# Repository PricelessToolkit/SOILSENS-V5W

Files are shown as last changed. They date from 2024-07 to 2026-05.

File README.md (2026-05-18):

<div align="center">
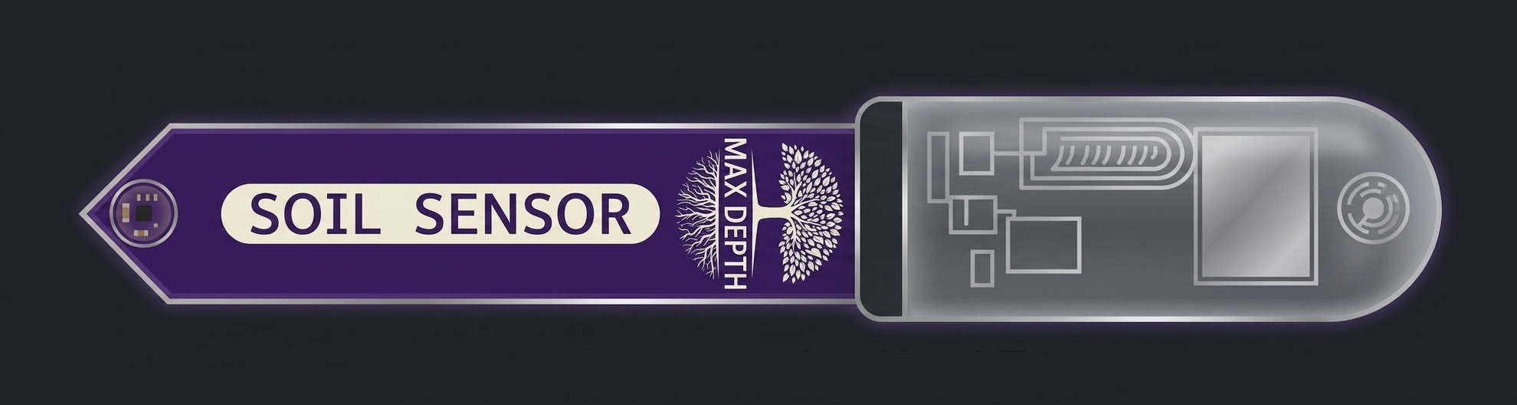
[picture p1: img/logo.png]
SoilSens-V5W
  

🤗 Please consider subscribing to my YouTube channel. Your subscription goes a long way toward supporting my work. If you would like to contribute even more, you can also buy me a coffee.
  
  [Shop](https://www.pricelesstoolkit.com) | [YouTube](https://www.youtube.com/watch?v=jbIuT4Cmzdk&t=36s)
  
</div>
<p align="center">
  <a href="https://ko-fi.com/U6U2QLAF8">
    
  </a>
</p>

____________

# Wireless "SOILSENS-V5W" and Wired ["SOILSENS-V5"](https://github.com/PricelessToolkit/SOILSENS-V5)

The SOILSENS-V5W is a wireless capacitive soil moisture sensor that supports both `ESP-NOW` and `Wi-Fi` connectivity. It also measures soil temperature, air temperature, air humidity, and ambient light. The capacitive sensing electrodes are embedded inside the PCB, which helps protect them from direct exposure. The sensor is compact, power-efficient, and designed for long-range communication in ESP-NOW mode. It can be configured without reflashing and supports MQTT auto-discovery through CapiBridge or direct Wi-Fi MQTT integration, making it fully compatible with Home Assistant.

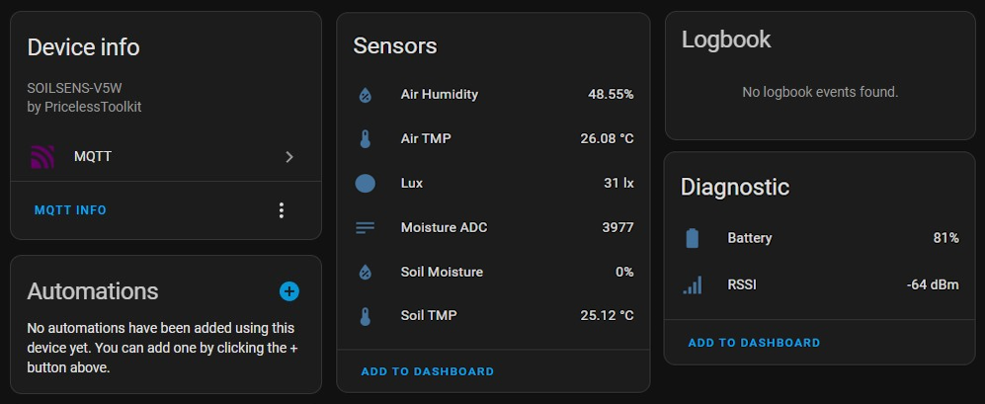
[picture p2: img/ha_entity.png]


## 🛒 Where to Buy https://www.PricelessToolkit.com

## 📣 Updates, Bugfixes, and Breaking Changes

- **18.04.2026** - Improved configuration portal and calibration workflow.
- - Added a cleaner configuration-only web UI with simpler setup for ESP-NOW, Fast-WIFI, and Basic-WIFI.
- - Added web-based soil calibration with live raw value preview plus dedicated Dry Soil and Wet Soil capture buttons.
- - Added Reset to Default directly inside the web interface, making recovery and reconfiguration easier.
- **12.03.2026** - Bugfix / compatibility update.
- - Fixed compilation for ESP32 Arduino Core v3.3.7 and AHT20 v1.0.2.
- - Tested with ArduinoJson v7.4.3, PubSubClient v2.8, and SparkFun TMP102 Breakout v1.1.2.
- **14.05.2025** - Added FailSafe, if it can't connect to WIFI or MQTT, it will power off after 15s.
- **21.03.2025** - Added Basic WIFI mode.

____________

## Product Specification

- **Microcontroller:**
   - ESP32-C3
- **Sensors:**
   - Soil Temperature: TMP102
   - Air Temperature and Humidity: AHT20
   - Light Sensor: ALS-PT19-315C
   - Soil Moisture: PCB Trace in the internal layer
- **Power:**
   - Uses a 1S LiPo battery with a PH2.0 connector
   - Requires an external 1S LiPo charger
- **Buttons:**
   - PRG (Programming)
   - RST (Reset)
   - CAL (Calibration)
   - TRG (Trigger)
- **LED Indicators:**
   - Green LED: Power indicator
   - Blue LED: Configuration mode indicator
- **Sensor Reading Interval:**
  - Default: 1 hour
  - Configurable: 5m, 10m, 30m, 1h, and 2h
  - Configuration Method: Adjustable via onboard PCB solder jumpers

### Required

- 1S 250mAh or less LiPo Battery (Connector PH2.0) 35x20x4mm MAX.
   - PricelessToolkit [1S 250mAh PH2.0](https://www.pricelesstoolkit.com/en/products/47-battery-li-po-37v-250mah-ph-20mm-2-pin.html)
   - https://s.click.aliexpress.com/e/_oBG0tjZ
   - https://s.click.aliexpress.com/e/_Dk14vS5
   - https://s.click.aliexpress.com/e/_DE5PfEV
   - Adafruit 150mAh https://www.adafruit.com/product/1317

> [!WARNING] 
> ⚠️ Ensure the battery connector has the correct polarity, as batteries from China sometimes come with random polarity. If it’s incorrect, you can manually swap the wires by gently lifting the plastic retainer on the pin, pulling the wire out, and then reversing the polarity before reinserting it.
> Connecting the battery with reverse polarity will damage the sensor permanently. Double-check the polarity before connecting the battery.

> [!NOTE]
> Lipo Polarity explanation "Adafruit Video" https://youtu.be/ILArrTIMFyM?si=WlTsnVo7XTozZ2FT

- 1S 4.20V LiPo charger.
  - PricelessToolkit [Micro-Charger](https://www.pricelesstoolkit.com/en/products/47-battery-li-po-37v-250mah-ph-20mm-2-pin.html)
  - Adafruit [Micro Lipo ](https://www.adafruit.com/product/1304)

> [!WARNING]  
> ⚠️ Ensure the charger’s maximum charging current does not exceed the battery’s capacity. For example, if the battery is 250mAh, the charger should have a maximum charging current of 250mA or less. Also, check the charger’s polarity, as it can sometimes be reversed.

###  In case of a Firmware update
- Aliexpress
  - [Pogo pin Clamp 6Pin 2.54mm spacing](https://s.click.aliexpress.com/e/_DEHExUb)
- PricelessToolkit
  - [Any 3.3v USB-UART Programmer](https://www.pricelesstoolkit.com/en/projects/33-uniprog-uartupdi-programmer-33v-0741049314412.html)

# Initial Power-On and Default Operation

- SOILSENS-V5W supports `ESP-NOW` and `Wi-Fi` operation.
- By default, the sensor starts in **ESP-NOW** mode.
- In this default mode, no initial setup is required if you are using a compatible [CapiBridge gateway](https://github.com/PricelessToolkit/CapiBridge).
- The default gateway key is `xy`.

| **Feature** | **ESP-NOW** | **Fast-WIFI** | **Basic-WIFI** |
|---|---|---|---|
| **Energy Efficiency** | Highly energy-efficient | ~3x Higher power consumption | ~10+x Higher power consumption |
| **Range** | Long-Range | Short range | Short range |
| **Configuration** | Does not require configuration | Requires network and MQTT configuration | Requires network and MQTT configuration |
| **Broadcasting** | Sensor data can be read from a third device without connecting to a network | Requires connection to a network | Requires connection to a network |
| **Gateway Requirement** | Requires a gateway [Capibridge](https://github.com/PricelessToolkit/CapiBridge) | Does not require a gateway | Does not require a gateway |

## Power Consumption
> [!NOTE]
> Measured using `Power Profiler Kit 2`, with a 250 mAh battery and a 1-hour wake-up interval.

| **Parameter** | **ESP-NOW** | **Fast-WIFI** | **Basic-WIFI** |
|---|---|---|---|
| **Active Duration (seconds)** | 0.55 seconds | 1.5 seconds | 1.5 - 10 seconds |
| **Current During Active Phase** | 40 mA | 47 mA | * |
| **Energy Consumption in Active Phase** | 0.006112 mAh | 0.02 mAh | * |
| **Inactive Duration** | 0.999847 hours | 0.99956 hours | * |
| **Energy Consumption in Inactive Phase** | 0.00007 mAh | 0.00007 mAh | * |
| **Total Energy Consumption** | 0.006182 mAh | 0.02007 mAh | * |
| **Total Hours of Operation** | 40,445 hours | 12,459 hours | * |
| **Total Days of Operation** | 1,685 days | 519 days | * |

(*) Depends on the network topology

## 1. Configuration

To access the configuration settings, follow these steps:

1. **Enter Configuration Mode**
   - Press and hold the **CAL** button.
   - While holding the **CAL** button, power the sensor or brefly press **TRG** button.
   - Keep holding the **CAL** button for more than 2 seconds, then release it.
   - The blue LED will blink, indicating that the sensor has entered configuration mode, the sensor creates a WiFi Access Point named `SOILSENS-V5W`.
   - Disconnect Celular connection "4G/5G" and Connect to `SOILSENS-V5W` WIFI hotspot.
   - Open a web browser and go to `http://192.168.4.1`.

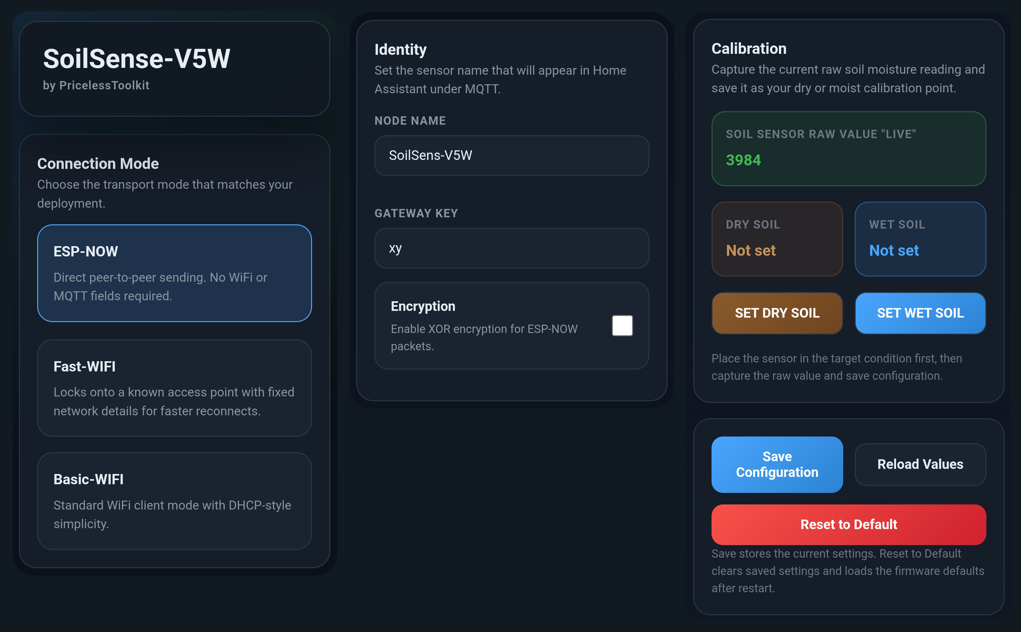
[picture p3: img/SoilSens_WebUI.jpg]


3. **Configure the Sensor in the Web UI**
   - **Connection Mode**
     - **ESP-NOW:** Uses direct ESP-NOW communication with the [CapiBridge gateway](https://github.com/PricelessToolkit/CapiBridge).
     - **Fast-WIFI:** Uses WiFi + MQTT with fixed network details for faster reconnects and lower power use than Basic-WIFI.
     - **Basic-WIFI:** Uses standard WiFi + MQTT setup with fewer required network fields.
   - **Identity**
     - **Sensor Name:** Set the name that will appear in Home Assistant under MQTT.
     - **Gateway Key:** Required only for ESP-NOW mode.
     - **ESP-NOW Encryption:** Optional. If enabled, enter the same key used by your gateway in this format: `["0x4B","0xA3","0x3F","0x9C"]`
   - **WiFi Access**
     - **WiFi SSID:** Enter your 2.4 GHz WiFi network name.
     - **Password:** Enter the WiFi password.
   - **Fast-WIFI Network Details**
     - **AP MAC Address:** Use the radio interface MAC address of your access point.
     - **WiFi Channel:** The channel must be fixed on the access point and must match the value entered here.
     - **Local IP:** Use a free IP address from your local network range and reserve it for the sensor.
     - **Gateway / Subnet:** Enter the network details that match your router.
   - **MQTT Broker**
     - Enter your MQTT server IP or hostname, port, username, and password.
     - In most Home Assistant installations, the MQTT server IP is the same as the Home Assistant IP, and the port is usually `1883`.

4. **Save or Reset**
   - Click **Save Configuration** to store the current settings and power off the sensor.
   - Click **Reload Values** to refresh the page and reload the currently saved values.
   - Click **Reset to Default** to clear all saved configuration and calibration values and return to the firmware defaults.

> [!NOTE]
> If the LED stays on after Saving configuration in WIFI mode, it means the sensor cannot connect because the SSID, Wi-Fi password, MAC address, Wi-Fi channel, or MQTT credentials are incorrect!

## 2. Calibrating the Soil Moisture Sensor

Accurate soil moisture readings require proper calibration. Follow these steps:

1. Insert the sensor into the dry soil.
   - **Optional** ( For best results, water the soil, wait a couple of days for the soil to settle around the sensor, and then dry out. )
2. Open the web configuration page as described in the configuration section above.
3. Go to the **Calibration** block.
4. Check **SOIL SENSOR RAW VALUE "LIVE"** and wait until the reading is stable.
5. For the dry calibration point:
   - Click **SET DRY SOIL**.
   - Click **Save Configuration** to store the dry calibration value.
6. For the wet calibration point:
   - Water the soil to the maximum moisture level you want to allow. **For best accuracy, let it soak for 5 - 10 minutes.**
   - Reopen the web configuration page as described in the configuration section above.
   - Click **SET WET SOIL**.
7. Click **Save Configuration** to store both calibration values.

> [!NOTE]
> For the best result, avoid moving the sensor during calibration. If the soil composition changes over time, or if sediment builds up around the probe, recalibration may be needed.

> [!IMPORTANT]
> ⚠️ Until dry and wet calibration values are saved, the moisture percentage will remain at `0`.

### WiFi Signal Strength

> [!NOTE]
>  Ensure the Wi-Fi signal strength at the installation point is strong and stable.

| RSSI (dBm) | Signal Quality | Description |
|---|---|---|
| -30 to -50 dBm  | Excellent | Very strong signal, ideal for stable data transmission |
| -51 to -60 dBm  | Good | Strong signal, generally reliable for data |
| -61 to -70 dBm  | Fair | Moderate signal, some minor issues possible, but usable |
| -71 to -80 dBm  | Poor | Weak signal, may experience some data drop |
| -81 to -90 dBm  | Very Poor | Very weak signal, frequent data drop likely |
| Below -90 dBm | Unusable | No effective connection, likely out of range |

## Programming Using Arduino IDE

1. Open the provided code in the Arduino IDE.
2. Install all required libraries.
```c
      
   #include <esp_now.h>
   #include <WiFi.h>
   #include "driver/adc.h"
   #include "esp_adc_cal.h"
   #include "Wire.h"
   #include <SparkFunTMP102.h>
   #include <ArduinoJson.h>
   #include <AHT20.h>
   #include <Preferences.h>
   #include <WebServer.h>
   #include <PubSubClient.h>
           
```
3. Select the appropriate board and port parameters. Refer to the screenshot below for the recommended settings.
       
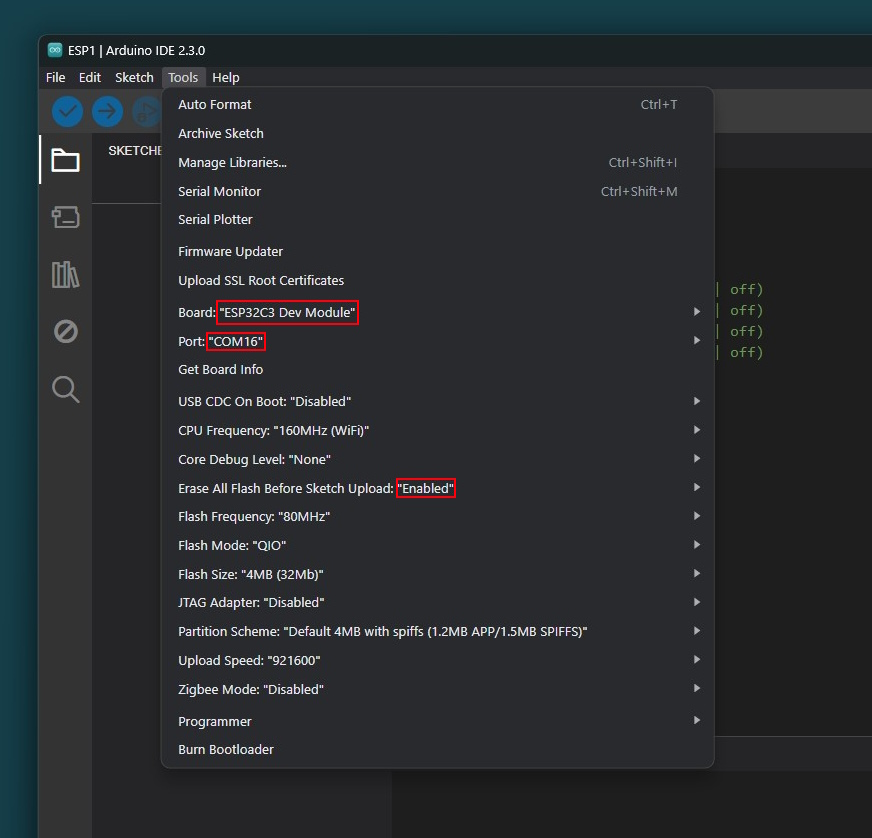
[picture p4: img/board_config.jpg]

       
4. Connect a 3.3V USB-to-TTL adapter to SOILSENS-V5W.

   | Sensor Pin | Adapter Pin |
   |------------|-------------|
   | TX         | RX          |
   | RX         | TX          |
   | 3V3        | 3V3         |
   | GND        | GND         |

5. Press and hold the **PRG** button on the sensor.
6. While holding **PRG**, connect the USB-to-TTL adapter to your computer.
7. Click **Upload** in the Arduino IDE.

## Frequently Asked Questions
### Why is my sensor giving inconsistent readings?
Due to the capacitive sensing principle, readings can vary based on soil moisture, tightness, and insertion depth. Repeated insertions might loosen the soil, affecting subsequent readings.

## 3. Wake-Up Interval

| Solder Jumpers | Interval Selection |
|---|---|
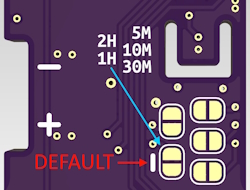
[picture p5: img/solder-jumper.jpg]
|  | You can change the interval by cutting the middle of the `1H` jumper and then bridging the desired jumper with solder. Available base intervals are `5m`, `10m`, `30m`, `1h`, and `2h`. Different combinations are also possible. [Parallel Resistor Calculator](https://www.digikey.fr/en/resources/conversion-calculators/conversion-calculator-parallel-and-series-resistor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) |

If you want to experiment with different wake-up intervals, you can also change the resistor value.

| Time Interval | Resistor Value (kΩ) | Time Interval | Resistor Value (kΩ) |
|---|---|---|---|
| 1 min | 22.00 | 10 min | 57.6 - soldered |
| 2 min | 29.349 | 20 min | 77.579 |
| 3 min | 34.729 | 30 min | 93.1 - soldered |
| 4 min | 39.097 | 40 min | 104.625 |
| 5 min | 42.2 - soldered | 50 min | 115.331 |
| 6 min | 46.301 | 1 h | 124.00 - soldered |
| 7 min | 49.392 | 1h 30min | 149.398 |
| 8 min | 52.224 | 2 h | 169.00 - soldered |
| 9 min | 54.902 |

> [!NOTE]
> The default wake-up interval is 1 hour. Reducing the interval will increase energy consumption.

# DIY

This project is open-source, so you can assemble SOILSENS-V5W yourself. To make the build easier, an interactive HTML BOM file is included in the `PCB` folder. It shows component placement and polarity to reduce assembly errors. A great deal of time and money has gone into making this project open-source. Support through purchasing a ready-made device from www.PricelessToolkit.com, subscribing to the YouTube channel, or buying me a coffee helps fund future projects.

## Schematic
<details>
  <summary>View schematic. Click here</summary>
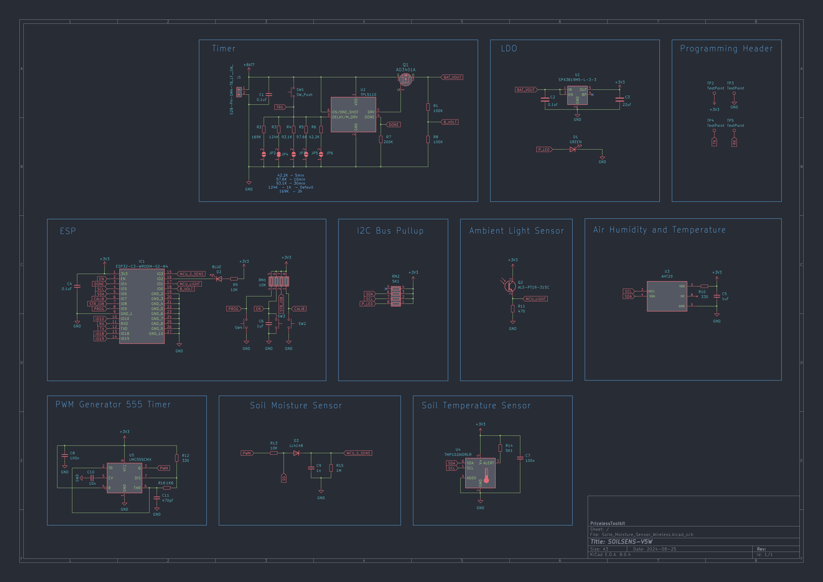
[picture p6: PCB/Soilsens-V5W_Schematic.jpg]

</details>

## 3D-Printed Case
The ideal case material is transparent and UV-resistant. ASA or white ABS is a good choice because it allows enough light to enter for the luminance sensor to work properly. For indoor use, translucent PETG can improve the luminance sensor range, and vent holes help the air temperature and humidity sensors work correctly. For outdoor use, a case without vent holes is recommended to reduce the risk of water ingress during heavy rain.
Glue for case https://s.click.aliexpress.com/e/_DcvGBY9

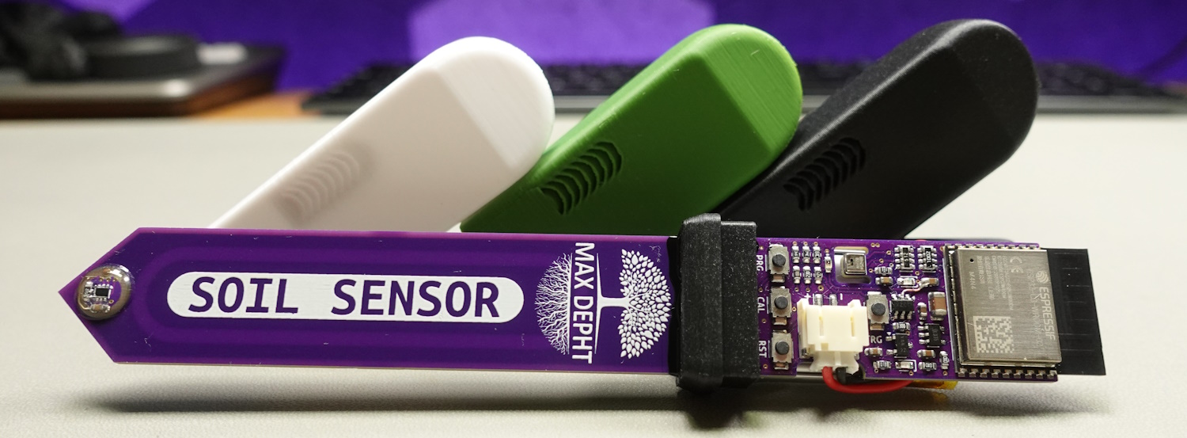
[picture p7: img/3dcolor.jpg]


## Troubleshooting

- Holding the calibration button.
    - More than 2 seconds opens configuration mode.
- When manually pressing the trigger button, the sensor may occasionally stay on and not power off if the button is not released quickly enough. If this happens, simply press the reset button.

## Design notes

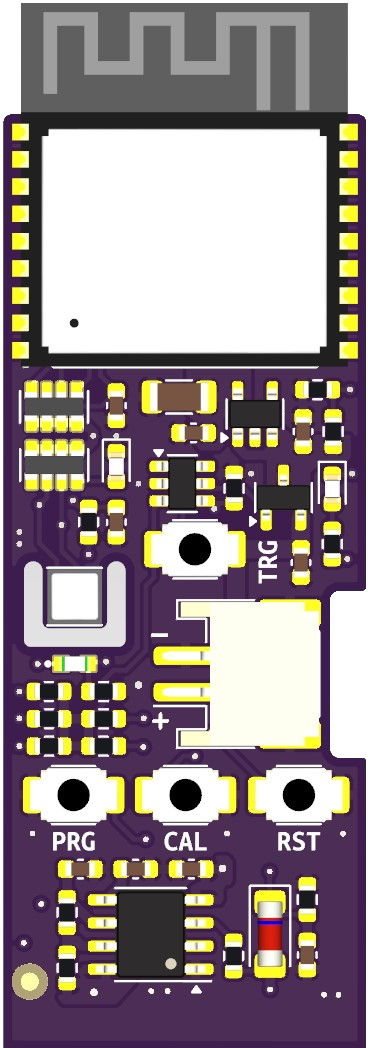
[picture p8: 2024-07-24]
img/sens-kc.png

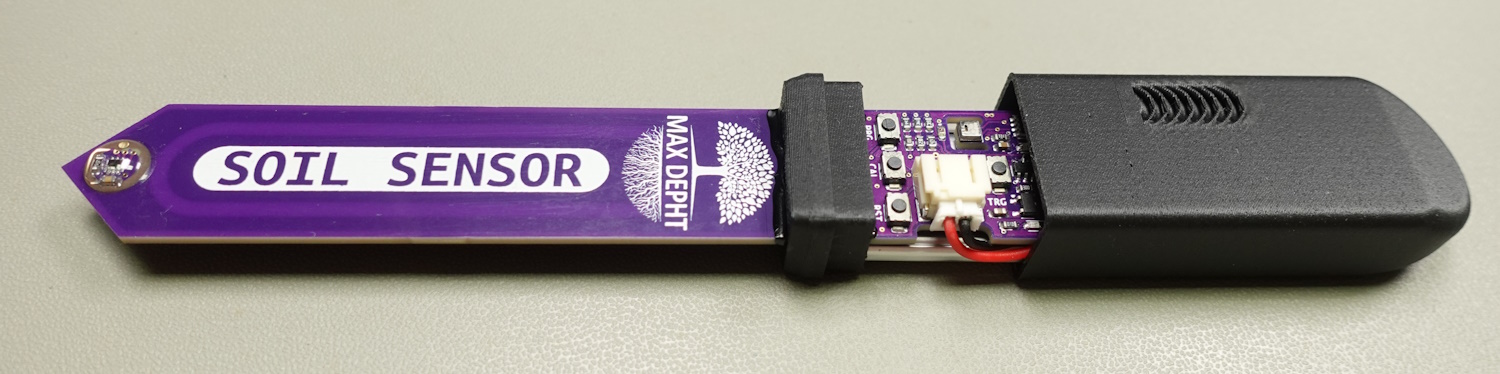
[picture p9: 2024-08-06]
img/header.jpg

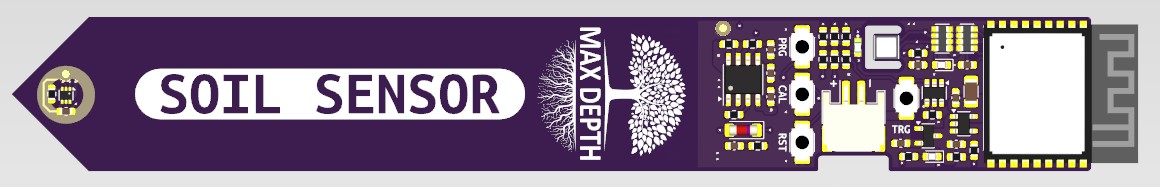
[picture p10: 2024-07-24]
img/sens-kc-full.jpg

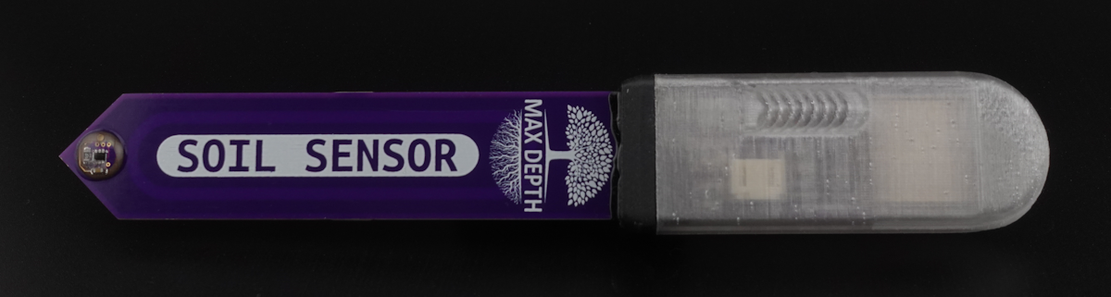
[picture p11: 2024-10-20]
img/sens-cap.png

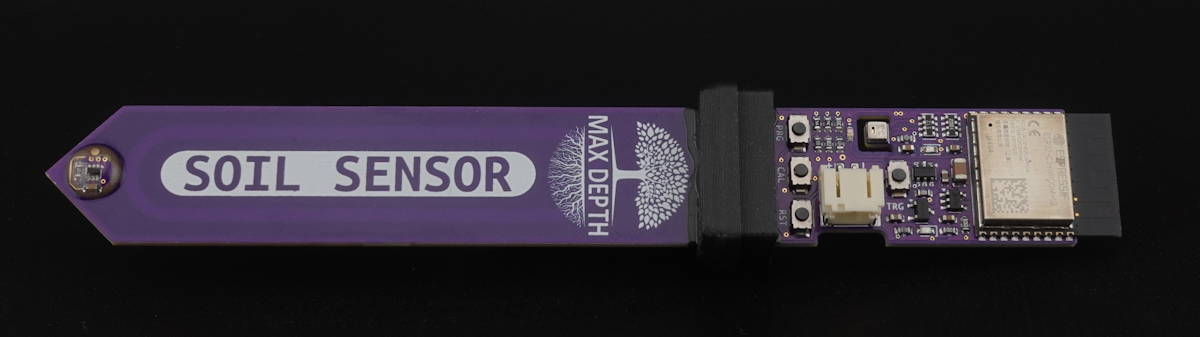
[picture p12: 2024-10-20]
img/sens-nk-pcb.png

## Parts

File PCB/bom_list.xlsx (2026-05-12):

Part ID | Part IPN | Part Name | Quantity | Reference | Supplier_0 | SKU_0
219 | CAP-000219-00 | Capacitor 0603_100nF_10%_50V_X7R - SMD/SMT ROHS | 5.0 | C1, C2, C4, C7, C8 | LCSC | C14663
263 | CAP-000263-00 | Capacitor 0603_1uF_10%_25V_X7R - SMD/SMT ROHS | 2.0 | C5, C6 | LCSC | C59302
334 | CAP-000334-00 | Capacitor 1206_22uF_10%_16V_X5R - SMD/SMT ROHS | 1.0 | C3 | LCSC | C90146
342 | CAP-000342-00 | Capacitor 0603_1nF_10%_50V_X7R - SMD/SMT ROHS | 1.0 | C9 | LCSC | C100040
23 | CAP-000023-00 | Capacitors 0603_10nF_5%_50V_X7R - SMD/SMT ROHS | 1.0 | C10 | LCSC Electronics | C115056
21 | CAP-000021-00 | Capacitors 0603_470pF_5%_50V_NP0 - SMD/SMT ROHS | 1.0 | C11 | LCSC Electronics | C106211
216 | RES-000216-00 | Resistor 0603_100K_1%_75V_100mW - Surface Mount ROHS | 2.0 | R1, R8 | LCSC | C14675
267 | RES-000267-00 | Resistor 0603_10K_1%_75V_100mW - Surface Mount ROHS | 2.0 | R9, R13 | LCSC | C25804
20 | RES-000020-00 | Resistors 0603_330R_1%_75V_100mW - Surface Mount ROHS | 2.0 | R10, R12 | LCSC Electronics | C105881
313 | RES-000313-00 | Resistor 0603_169K_1%_75V_100mW 100ppm/℃ - Surface Mount ROHS | 1.0 | R2 | LCSC Electronics | C137791
11 | RES-000011-00 | Resistors 0603_124K_1%_75V_100mW - Surface Mount ROHS | 1.0 | R3 | LCSC Electronics | C22788
315 | RES-000315-00 | Resistor 0603_93.1K_1%_75V_100mW - Surface Mount ROHS | 1.0 | R4 | LCSC | C2933266
316 | RES-000316-00 | Resistor 0603_57.6K_1%_75V_100mW - Surface Mount ROHS | 1.0 | R5 | LCSC | C2933240
317 | RES-000317-00 | Resistor 0603_42.2K_1%_75V_100mW - Surface Mount ROHS | 1.0 | R6 | LCSC | C273741
312 | RES-000312-00 | Resistor 0603_200K_1%_75V_100mW - Surface Mount ROHS | 1.0 | R7 | LCSC | C105574
340 | RES-000340-00 | Resistors 0603_470R_1%_75V - Surface Mount ROHS | 1.0 | R11 | LCSC | C23179
208 | RES-000208-00 | Resistor 0603_5.1K_1%_50V_100mW - Surface Mount ROHS | 1.0 | R14 | LCSC | C2907044
271 | RES-000271-00 | Resistor 0603_1M_1%_75V_100mW - Surface Mount ROHS | 1.0 | R15 | LCSC | C105578
19 | RES-000019-00 | Resistors 0603_1.6K_1%_75V_100mW - Surface Mount ROHS | 1.0 | R16 | LCSC Electronics | C2930052
53 | DIO-000053-00 | LED 0603_55mW_Yellow-Green - ROHS | 1.0 | D1 | LCSC | C965805
201 | DIO-000201-00 | LED 0603_80mW_Blue XL-1608UBC-04 ROHS | 1.0 | D2 | LCSC | C965807
341 | DIO-000341-00 | Switching Diode LL4148_LL-34_75V 1V@10mA 4ns 200mA LL-34 ROHS | 1.0 | D3 | LCSC | C3011166
64 | PWR-000064-00 | Voltage Regulator SPX3819M5-L-3-3/TR 3.3V 500mA SOT-23-5 (LDO) ROHS | 1.0 | U1 | LCSC Electronics | C9055
73 | ICS-000073-00 | Timer TPL5110DDCT 1.8V~5V SOT-23-6 ROHS | 1.0 | U2 | LCSC Electronics | C125830
339 | ICS-000339-00 | SMD Temperature and Humidity Sensor ROHS | 1.0 | U3 | LCSC | C2757850
336 | ICS-000336-00 | Temperature Sensor TMP102AIDRLR -40℃~+125℃ I2C ±0.5℃ SOT-563 ROHS | 1.0 | U4 | LCSC | C99269
338 | ICS-000338-00 | LMC555M/TR 2-18V SOP-8 Timers ROHS | 1.0 | U5 | LCSC | C356725, C90760, C19193414
122 | MEC-000122-00 | Tactile Switche TS342A2P-WZ NO 50mA Brick nogging SPST SMD ROHS | 4.0 | SW1, SW2, SW3, SW4 | LCSC Electronics | C557591
273 | WIFI-000273-00 | WIFI Module ESP32-C3-WROOM-02-N4 4MB SPI flash, PCB antenna, -40 C +85 C SMD | 1.0 | IC1 | Mouser | 356-ESP32C3WROOM02N4
80 | TRA-000080-00 | MOSFET P-Channel AO3401A 30V 4.2A SOT-23 ROHS | 1.0 | Q1 | LCSC Electronics | C306862
202 | ICS-000202-00 | Ambient Light Sensor ALS-PT19-315C/L177/TR8 0603 SMD ROHS | 1.0 | Q2 | LCSC | C146233
291 | RES-000291-00 | Resistor Network 0603x4_10k_1% 62.5mW ROHS | 1.0 | RN1 | LCSC | C110924
301 | RES-000301-00 | Resistor Network 0603x4_5.1K_5%_62.5mW ±200ppm/℃ ROHS | 1.0 | RN2 | LCSC | C12028
60 | CON-000060-00 | Connector 1x2P_PH_2A_P2mm_Male - ROHS | 1.0 | J1 | LCSC Electronics | C295747
353 |  | SOILSENS-V5W_PCB | 1.0 | PCB
354 |  | SOILSENS-V5W_3D_Enclosure | 1.0

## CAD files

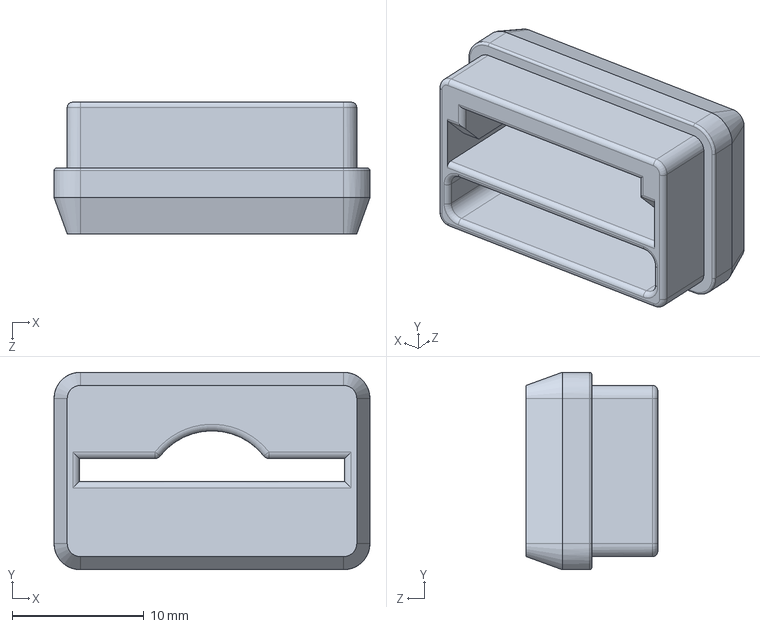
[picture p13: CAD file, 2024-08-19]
3D/SoilSens-V5W_Base_DIY.SLDPRT
24.0 x 15.0 x 10.0 mm

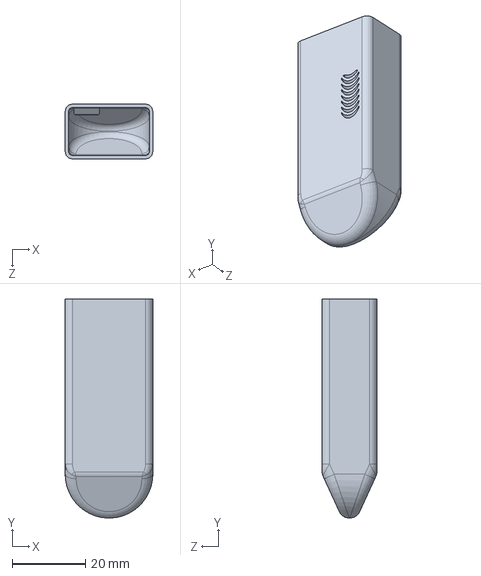
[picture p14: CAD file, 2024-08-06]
3D/SoilSens-V5W_Top_Vent.SLDPRT
24.0 x 60.0 x 15.0 mm

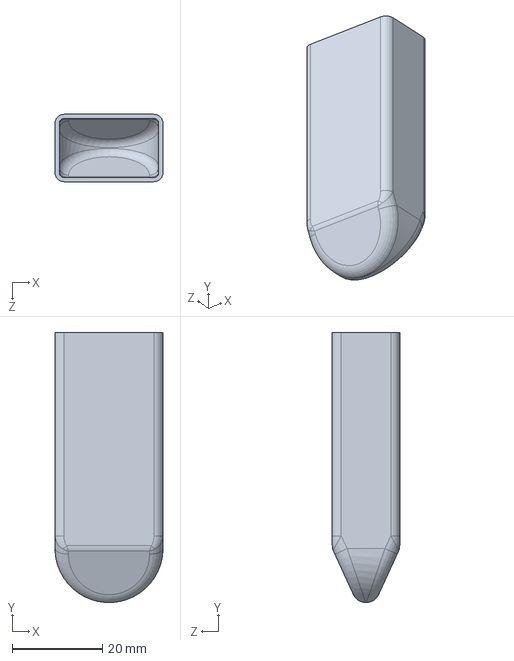
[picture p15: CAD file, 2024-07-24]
3D/SoilSens-V5W_Top.SLDPRT
24.0 x 60.0 x 15.0 mm

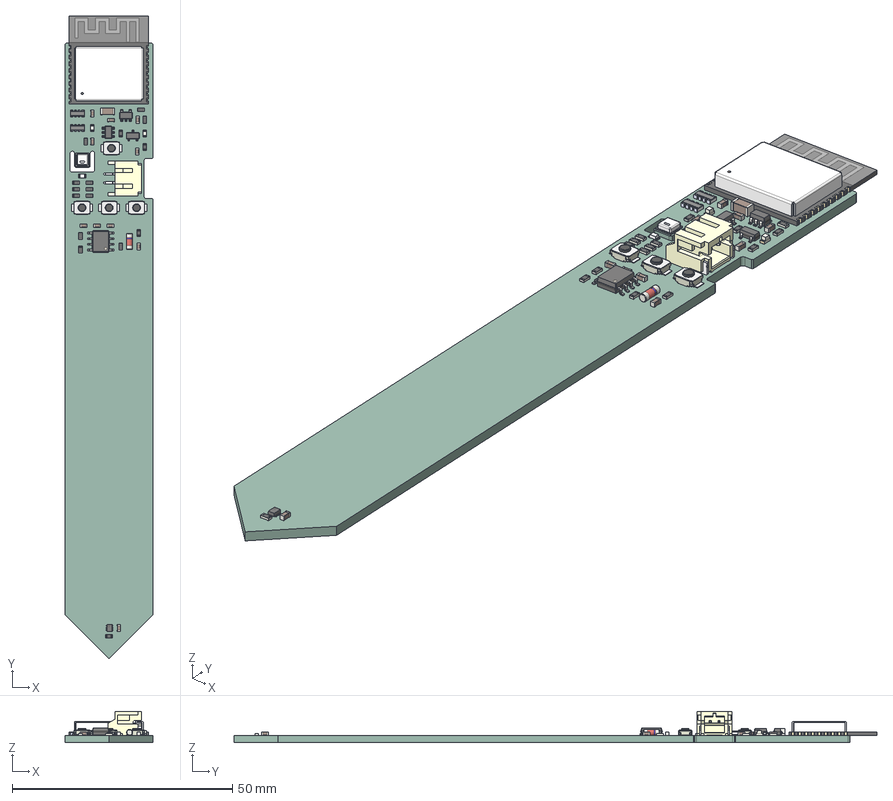
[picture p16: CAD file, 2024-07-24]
3D/Soile_Moisture_Sensor_Wireless.step
20.0 x 146.1 x 7.15 mm
C_0603_1608Metric x 10
R_0603_1608Metric x 16
ALS-PT19-315C(slash)L177(slash)TR8
SW_SPST_B3U-1000P x 4
D_MiniMELF_Standard
SOT-23-3
S2B-PH-SM4-TB(LF)(SN)
SOT_563
SOIC_8_39x49mm_P127mm
YC164-JR-0720KL x 2
LED_0603_1608Metric x 2
SOT_23_6
C_1206_3216Metric
ESP32-C3-WROOM-02-N4
SOT_23_5
AHT20 Sensor v0
_autosave-Soile_Moisture_Sensor_Wireless_PCB

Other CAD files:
3D/SoilSens-V5W_Base.SLDPRT
3D/SoilSens-V5W_Base.STL
3D/SoilSens-V5W_Base_DIY.STL
3D/SoilSens-V5W_Top.STL
3D/SoilSens-V5W_Top_Vent.STL
3D/Soile_Moisture_Sensor_Wireless.SLDASM

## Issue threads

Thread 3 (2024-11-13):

kicad files missing

shufps, 2024-11-13:
It seems there are no KiCad files in the repository.

PricelessToolkit, 2024-11-13:
I don't share KiCad files; only Gerber files and the BOM are provided for self-assembly.

shufps, 2024-11-14:
Why not?

"Copy protection" doesn't make sense because I can replicate your entire KiCad project from your schematic and pictures on a single day.

It's just annoying having to do this but it actually doesn't protect anything by not publishing it :thinking:

PricelessToolkit, 2024-11-14:
1. It protects from generating a 'PnP placement file' and from logo swappers. 2. I’d rather not have to explain my routing choices every two minutes or hear critiques on how it 'should' be done, one or two suggestions per project are fine, but every passerby seems to have a new idea, and I simply don’t have the time. I share the Gerbers for the Home Assistant community, so if someone prefers not to buy the assembled version, they can assemble it themselves as a more affordable option.

Closed 2024-11-13.

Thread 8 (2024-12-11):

MQTT auto-discovery not working with Capibridge

ppkstat, 2024-12-11:
I just finished building my Soilsens. The device appears to function correctly but it is not discovered by MQTT in home assistant.
This is what is beeing received by the Capibridge when triggered:
ESP-NOW Message: {"k":"xy","id":"Soilsens Autopot ","b":65,"l":26,"mo":0,"t":18,"t2":18,"hu":54}

and this is a screenshot of the MQTT explorer:
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

PricelessToolkit, 2024-12-11:
1. Is your Capibridge key "xy"? , make sure that capibridge and soilsens has the same key.
2. "Soilsens Autopot " remove spaces, from the middle and from the end "Soilsens-Autopot" I will add this in the manual!

Closed 2024-12-11.

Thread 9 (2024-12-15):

Soilsens V5W - Text Sensor

DirkTas67, 2024-12-15:
Hello,

I was wondering what the Text sensor is for the Soilsens v5w, I don't know if you shipped it this way to me but I had some problems installing the sensor, I eventualy had to 'reset' it with the 'plugin power/hold the calibration button' trick before it worked but that was after I re-installed the firmware, so now I have a text sensor that is changing rapidly and I wonder if this is good for the battery (still don't have a battery, it is powered directly from usb via pogo pins).

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

DirkTas67, 2024-12-15:
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

This is what the serial monitor tells us.

PricelessToolkit, 2024-12-15:
Hi, Thank you for supporting my work!
The "text" sensor is a raw ADC reading from the "moisture sensor." It can be handy for checking calibration. The serial output is normal but can appear to freak out because the sensor sends data too quickly, with no delay between readings. This happens because you powered it from the programming port, so the sensor can't "unplug itself" from power after sending data once. When you power it with a battery, it will work properly.

Closed 2024-12-16.

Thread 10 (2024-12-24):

Wrong silk mask text

BoguslavskyiR, 2024-12-24:
During flashing first board was discovered that UART contacts have wrond naming

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

PricelessToolkit, 2024-12-24:
Strange. Are you sure that the pinout name on your programmer is correct?

TP4 is TX and it is current.
 https://github.com/PricelessToolkit/SOILSENS-V5W/blob/main/PCB/Soilsens-V5W_Schematic.jpg

BoguslavskyiR, 2024-12-24:
I will double check, but it's not the first time I have used this adapter (DFrobot dfr0065).
But i will check again with another adapter

PricelessToolkit, 2024-12-24:
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

BoguslavskyiR, 2024-12-24:
In this case sorry, but it's very strange, I've been using this dongle for a long time with the rx->tx connection.

PricelessToolkit, 2024-12-24:
No need to apologize! It's all good I’m here for help. If you want to check it yourself, just snap a photo, zoom in, and follow the PCB trace from pin 5. Unfortunately, I couldn’t find a high-quality photo, but this one is the best I’ve seen so far:
https://m.media-amazon.com/images/I/6115v8bCfbL._AC_SL1000_.jpg

Closed 2024-12-24.

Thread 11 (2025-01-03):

Battery

DirkTas67, 2025-01-03:
Hello,

I received 2 sensors yesterday. I added a 250mah battery on one of the sensors and a 200mah on the other sensor. I charged both of them fully and installed then on the sensors and then calibrated the sensors. The one with the 250mah battery showed 100% battery, the one with the 200mah battery showed 85% battery. I then put them in place. a day later the one with the 200mah battery shows now 14% battery and the one with the 250mah battery shows 45%.

update time is still 1 hour.

Is this normal?

Regards Dirk

DirkTas67, 2025-01-03:
I forgot to mention that both of them are working is ESPNOW modus

PricelessToolkit, 2025-01-03:
The green LED always stays on?

DirkTas67, 2025-01-03:
No, the green led is off

PricelessToolkit, 2025-01-03:
If the LED is off, the consumption is 400nAh, so the consumption you describe is impossible. If it turns on every hour, it stays on for approximately 500ms. It basically can't consume that amount of power. When you check the serial output of CapiBridge, is the battery percentage the same as in Home Assistant? and can you check the voltage on battery?

DirkTas67, 2025-01-06:
Ok, after 2 days both batteries were empty.

Second try, charged the 200mah battery again and installed it, it showed 81% but now after 2 days it still shows 81%, this is allready a great improvement, just charged the 250mah battery and inserted it and this one shows 100%, maybe it was just a reset thing. I installed the batteries, calibrated the sensor for correct moisture and placed them in the ground. Maybe a reset is needed. In a few days I check again and let you know.

PricelessToolkit, 2025-01-06:
Even if you don't connect a freshly charged battery (4.20V), after a couple of days, its voltage sags slightly, typically to around ~4.12V. This is a 1-2% drop, depending on the battery's freshness and quality. However, after that, the voltage will stabilize.

An 81% reading on a 4.2V battery is unusual and could be due to variations in the voltage divider resistors. If it bothers you, it can be calibrated by reflashing the firmware.

PricelessToolkit, 2025-01-14:
Does everything work as intended? can I close This issue?

Closed 2025-01-15.

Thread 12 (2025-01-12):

Support for MQTTS and CNAME

tnesztler, 2025-01-12:
# Context

MQTT server is exposed behind a reverse proxy for SSL termination.
This results in the MQTT port being 8883 (default for MQTTS) and hostname being a CNAME, not an IP.

I personally had to expose my MQTT server via a direct IP and standard TCP port (1883) to make it compatible with the soil sensor which is not ideal as that leaves the communication un-encrypted on the air.

Could we make on boot a single DNS request to get the IP, validate the SSL certificate and connect to the MQTT server?
Would that work while keeping power consumption low?

PricelessToolkit, 2025-01-14:
Hmm, I never used SSL with the PubSubClient library, I will do some research.  autonomy will decrease slightly due to longer uptime "maybe 50ms more"

Closed 2025-01-19.

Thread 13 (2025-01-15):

Traces too close for solder mask

l30ns, 2025-01-15:
I'm sure you know this already, but in your design the traces for the temp sensor at the tip of the board (U4) are too close together (0,16mm) and it makes PCBway to freak out.

They say the distance between ICs need to be >0,19mm to produce the solder mask. Thought you might want to either fix that or add a warning in your DIY project description.
P.S. This is a copy of reddit msg. Figured out you would want it here.

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

PricelessToolkit, 2025-01-15:
Hi, thanks for posting here. It’s a small IC, so I can’t change the distance between the legs. Regarding the solder mask, the 'blue ring' area is without a solder mask to improve epoxy resin adherence. Under U4, having a solder mask is a normal practice as it helps reduce the chance of solder bridges. It can be done without it, but it’s not recommended.

PS: can you share the link to the Reddit post?

Closed 2025-01-19.

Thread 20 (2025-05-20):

Sensor LED stays green and sensor does not react to any input

mvbjrn, 2025-05-20:
Hi!

I just bought the sensor and powered it via a battery from your shop. The LED stays green and the sensor is not reacting to any input. I initially were able to configure the sensor, it shows up in my WIFI but is not putting out any MQTT messages.

Unplugging the battery and putting it back in did not change anything.

Any advise on what I can do now? 😅

PricelessToolkit, 2025-05-20:
1. Reconfigure it because if the green LED stays on = it can't connect to WIFI or MQTT.
3.  If it is difficult to configure in Fast WIFI mode, you can reflash it. "I added the new basec wifi mode to the firmware."

mvbjrn, 2025-05-21:
Resetting the sensor did the trick. I was able to configure fast WIFI mode.

It may be handy to add a trouble shooting section to the README and also add some details about "how to reset" there.

Thanks a lot!

Closed 2025-05-21.

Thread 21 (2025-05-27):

Via distance smaller than required 0.19mm

maxhoheiser, 2025-05-27:
Hi, I am running into an issue on PCBWay where the distance between two copper vias is smaller than 0.19mm. Did you face similar issues?

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

PricelessToolkit, 2025-05-27:
Hi, it's not actually a via, it's the distance between physical component pads, which can't be changed as it's defined by the component footprint. Are they raising the issue due to solder mask clearance? If so, it's okay, they can proceed as is.

Closed 2025-05-27.

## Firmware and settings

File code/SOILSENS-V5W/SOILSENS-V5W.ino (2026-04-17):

#include <esp_now.h>
#include <WiFi.h>
#include "driver/adc.h"
#include "esp_adc_cal.h"
#include "Wire.h"
#include <SparkFunTMP102.h>
#include <ArduinoJson.h>
#include <AHT20.h>
#include <Preferences.h>
#include <WebServer.h>
#include <PubSubClient.h>
#include <math.h>
#include "espnow_encryption.h"

#define DEFAULT_VREF 1100
#define MQTT_RETAIN true
#define SENSOR_TOPIC "homeassistant/sensor/"

uint8_t receiverAddress[] = {0xFF, 0xFF, 0xFF, 0xFF, 0xFF, 0xFF}; // ESP-NOW Receiver MAC "BROADCAST"

AHT20 aht20;
TMP102 sensor0;
Preferences preferences;

bool inCalibrationMode = false;
const int calibrationButtonPin = 7;
const int blueLEDPin = 2;
const int soilMoisturePin = 3;

unsigned long BootTime;
const unsigned long maxPressTime = 2000;

unsigned int drySoilValue;
unsigned int wetSoilValue;

int light;
int batteryPercentage = 0;
int soilMoistureRow = 0;
int soilMpercent = 0;
String node_name;
String gateway_key;
String wifi_ssid;
String wifi_password;
String mqtt_server;
String wifi_local_ip;
String gateway;
String subnet;
String mac_address;
unsigned int mqtt_port;
String mqtt_username;
String mqtt_password;
unsigned int wifi_channel;
unsigned int config_mode; // 1: ESP-NOW, 0: Fast-WIFI, 2: Basic-WIFI
bool espnow_encryption_enabled = false;
String espnow_encryption_key;

StaticJsonDocument<256> doc;

typedef struct struct_message {
  char json[256];
} struct_message;

struct_message myData;

WiFiClient espClient;
PubSubClient client(espClient);

unsigned long toggleStartTime = 0;
bool mqttPublished = false;

// Forward declarations
void setupSensorConfig();
void fast_setup_wifi();
void basic_setup_wifi();
void reconnect();
int getAverageSoilMoisture();
int getAverageVoltage();
void blinkLED(int times, int interval);
void toggleDonePin();
void FailSafe();
void modeESPNOW();
void mqttautodiscovery();
void publishmqtt();
float readAHT20Temperature();
float readAHT20Humidity();
String htmlEscape(const String &value);

#if defined(ESP_ARDUINO_VERSION_MAJOR) && ESP_ARDUINO_VERSION_MAJOR >= 3
void OnDataSent(const wifi_tx_info_t *info, esp_now_send_status_t status) {
  toggleDonePin();
}
#else
void OnDataSent(const uint8_t *mac_addr, esp_now_send_status_t status) {
  toggleDonePin();
}
#endif

float readAHT20Temperature() {
  return aht20.getTemperature();
}

float readAHT20Humidity() {
  return aht20.getHumidity();
}

String htmlEscape(const String &value) {
  String escaped = value;
  escaped.replace("&", "&amp;");
  escaped.replace("\"", "&quot;");
  escaped.replace("<", "&lt;");
  escaped.replace(">", "&gt;");
  return escaped;
}

////////////// HOTSPOT CONFIGURATION ////////////

void setupSensorConfig() {
  const char *ssidAP = "SoilSens-V5W";
  const char *passwordAP = "password";

  WiFi.mode(WIFI_AP);
  WiFi.softAP(ssidAP, passwordAP);

  Serial.println("Access Point started");
  Serial.print("IP address: ");
  Serial.println(WiFi.softAPIP());

  preferences.begin("wifi-config", false);
  preferences.end();
  preferences.begin("soilCalib", true);
  drySoilValue = preferences.getUInt("drySoilValue", 0);
  wetSoilValue = preferences.getUInt("wetSoilValue", 0);
  preferences.end();
  preferences.begin("wifi-config", false);

  WebServer server(80);

  String htmlForm = R"rawliteral(
<!DOCTYPE html>
<html lang="en" data-theme="dark">
<head>
  <meta charset="utf-8">
  <meta name="viewport" content="width=device-width, initial-scale=1">
  <title>SoilSens-V5W Configuration</title>
  <style>
    :root{--bg-primary:#0a0e14;--bg-secondary:#111821;--bg-tertiary:#1a232f;--bg-card:#151d28;--bg-card-hover:#1a2636;--border-primary:#2a3744;--border-accent:#3d4f5f;--text-primary:#e6edf3;--text-secondary:#8b949e;--text-muted:#6e7681;--accent-primary:#49A6FD;--accent-secondary:#2c83d3;--accent-glow:rgba(73,166,253,0.16);--success:#3fb950;--warning:#d29922;--danger:#f85149;--shadow-md:0 24px 60px rgba(0,0,0,0.45)}
    *{margin:0;padding:0;box-sizing:border-box}
    body{font-family:-apple-system,BlinkMacSystemFont,"Segoe UI",sans-serif;background:
      radial-gradient(circle at top left,rgba(73,166,253,0.16),transparent 28%),
      radial-gradient(circle at top right,rgba(63,185,80,0.08),transparent 24%),
      linear-gradient(180deg,#0a0e14 0%,#101722 100%);color:var(--text-primary);min-height:100vh;line-height:1.5}
    .shell{max-width:1160px;margin:0 auto;padding:28px 18px 40px}
    .hero{display:block;margin-bottom:18px}
    .hero-card,.panel{background:rgba(17,24,33,0.92);border:1px solid var(--border-primary);border-radius:20px;box-shadow:var(--shadow-md);backdrop-filter:blur(6px)}
    .hero-card{padding:24px}
    .hero-title{margin:0;font-size:clamp(28px,4vw,44px);line-height:1.05}
    .hero-subtitle{display:block;margin-top:6px;font-size:clamp(12px,2vw,16px);line-height:1.2;color:var(--text-secondary);font-weight:600;letter-spacing:.04em}
    .eyebrow{display:inline-flex;align-items:center;gap:8px;padding:6px 10px;border-radius:999px;background:var(--accent-glow);color:var(--accent-primary);font-size:12px;font-weight:700;letter-spacing:.08em;text-transform:uppercase}
    .mode-grid,.field-grid{display:grid;gap:16px}
    .mode-grid{grid-template-columns:repeat(3,minmax(0,1fr))}
    .field-grid.two{grid-template-columns:repeat(2,minmax(0,1fr))}
    .section{background:var(--bg-card);border:1px solid var(--border-primary);border-radius:18px;padding:18px;margin-bottom:16px}
    .section-head{display:flex;justify-content:space-between;gap:12px;align-items:flex-start;margin-bottom:14px}
    .section-title{font-size:16px;font-weight:700}
    .section-copy{color:var(--text-secondary);font-size:13px;max-width:520px}
    .mode-card{position:relative}
    .mode-card input{position:absolute;opacity:0;pointer-events:none}
    .mode-option{display:block;height:100%;padding:16px;border-radius:16px;background:var(--bg-tertiary);border:1px solid var(--border-primary);cursor:pointer;transition:transform .2s,border-color .2s,background .2s}
    .mode-option strong{display:block;font-size:15px;margin-bottom:6px}
    .mode-option span{display:block;color:var(--text-secondary);font-size:13px}
    .mode-card input:checked + .mode-option{border-color:var(--accent-primary);background:var(--accent-glow);transform:translateY(-2px)}
    .form-group{margin-bottom:14px}
    .form-label{display:block;font-size:12px;font-weight:700;color:var(--text-secondary);margin-bottom:6px;text-transform:uppercase;letter-spacing:.06em}
    .form-input{width:100%;padding:12px 14px;border-radius:12px;border:1px solid var(--border-primary);background:var(--bg-tertiary);color:var(--text-primary);font-size:14px;transition:border-color .2s,box-shadow .2s}
    .form-input:focus{outline:none;border-color:var(--accent-primary);box-shadow:0 0 0 4px rgba(73,166,253,0.12)}
    .toggle-row{display:flex;align-items:center;justify-content:space-between;gap:14px;padding:14px 16px;border-radius:14px;background:var(--bg-tertiary);border:1px solid var(--border-primary);margin-bottom:14px}
    .toggle-copy strong{display:block;font-size:14px;margin-bottom:4px}
    .toggle-copy span{display:block;color:var(--text-secondary);font-size:12px}
    .toggle-input{width:22px;height:22px;accent-color:var(--accent-primary);flex-shrink:0}
    .form-hint{font-size:12px;color:var(--text-muted);margin-top:6px}
    .pill{display:inline-flex;align-items:center;gap:8px;padding:8px 12px;border-radius:999px;background:rgba(63,185,80,0.12);color:var(--success);font-size:12px;font-weight:700}
    .pill::before{content:"";width:8px;height:8px;border-radius:999px;background:currentColor}
    .actions{display:flex;gap:12px;flex-wrap:wrap;align-items:center}
    .settings-actions{flex-wrap:nowrap;margin-bottom:12px}
    .calibration-actions{margin-bottom:16px;flex-wrap:nowrap}
    .btn{appearance:none;border:none;border-radius:12px;padding:13px 18px;font-size:14px;font-weight:700;cursor:pointer;transition:transform .2s,opacity .2s}
    .btn-primary{background:linear-gradient(135deg,var(--accent-primary),var(--accent-secondary));color:#fff}
    .btn-secondary{background:var(--bg-tertiary);color:var(--text-primary);border:1px solid var(--border-primary)}
    .btn-danger{background:linear-gradient(135deg,#f85149,#cf222e);color:#fff}
    .btn-half{flex:1 1 50%;width:50%}
    .btn-full{width:100%;justify-content:center}
    .btn-calibration{flex:1 1 50%;width:50%;color:#fff}
    .btn-dry{background:linear-gradient(135deg,#8a5a2b,#6f451f)}
    .btn-wet{background:linear-gradient(135deg,var(--accent-primary),var(--accent-secondary))}
    .status-row{display:grid;grid-template-columns:repeat(3,minmax(0,1fr));gap:12px;margin-bottom:16px}
    .status-row.two-col{display:grid;grid-template-columns:minmax(0,1fr) minmax(0,1fr) !important;align-items:stretch}
    .status-chip{padding:14px;border-radius:14px;background:var(--bg-tertiary);border:1px solid var(--border-primary)}
    .status-chip strong{display:block;font-size:12px;color:var(--text-muted);text-transform:uppercase;letter-spacing:.06em;margin-bottom:6px}
    .status-chip span{display:block;font-size:16px;font-weight:700;word-break:break-word}
    .status-chip.live-chip{border-color:rgba(63,185,80,.35);background:rgba(63,185,80,.10)}
    .status-chip.live-chip span{color:var(--success)}
    .status-chip.dry-chip{border-color:rgba(138,90,43,.38);background:rgba(138,90,43,.16)}
    .status-chip.dry-chip span{color:#c79057}
    .status-chip.moist-chip{border-color:rgba(73,166,253,.35);background:rgba(73,166,253,.12)}
    .status-chip.moist-chip span{color:var(--accent-primary)}
    .btn:hover{transform:translateY(-1px)}
    .footer-note{color:var(--text-muted);font-size:12px}
    .conditional{display:none}
    .conditional.show{display:block}
    @media (max-width:900px){.mode-grid,.field-grid.two,.status-row{grid-template-columns:1fr}}
  </style>
</head>
<body>
  <div class="shell">
    <section class="hero">
      <div class="hero-card">
        <h1 class="hero-title">SoilSense-V5W<span class="hero-subtitle">by PricelessToolkit</span></h1>
      </div>
    </section>

    <form action="/submit" method="post">
      <section class="section">
        <div class="section-head">
          <div>
            <div class="section-title">Connection Mode</div>
            <div class="section-copy">Choose the transport mode that matches your deployment.</div>
          </div>
        </div>
        <div class="mode-grid">
          <label class="mode-card">
            <input type="radio" id="mode1" name="mode" value="1" __MODE_1__>
            <span class="mode-option"><strong>ESP-NOW</strong><span>Direct peer-to-peer sending. No WiFi or MQTT fields required.</span></span>
          </label>
          <label class="mode-card">
            <input type="radio" id="mode0" name="mode" value="0" __MODE_0__>
            <span class="mode-option"><strong>Fast-WIFI</strong><span>Locks onto a known access point with fixed network details for faster reconnects.</span></span>
          </label>
          <label class="mode-card">
            <input type="radio" id="mode2" name="mode" value="2" __MODE_2__>
            <span class="mode-option"><strong>Basic-WIFI</strong><span>Standard WiFi client mode with DHCP-style simplicity.</span></span>
          </label>
        </div>
      </section>

      <section class="section">
        <div class="section-head">
          <div>
            <div class="section-title">Identity</div>
            <div class="section-copy">Set the sensor name that will appear in Home Assistant under MQTT.</div>
          </div>
        </div>
        <div class="field-grid two">
          <div class="form-group">
            <label class="form-label" for="nodeName">Node Name</label>
            <input class="form-input" type="text" id="nodeName" name="nodeName" value="__NODE_NAME__">
          </div>
          <div class="form-group conditional" id="gatewayKeyField">
            <label class="form-label" for="gatewayKey">Gateway Key</label>
            <input class="form-input" type="text" id="gatewayKey" name="gatewayKey" value="__GATEWAY_KEY__">
          </div>
        </div>
        <div class="conditional" id="espNowEncryptionBlock">
          <div class="toggle-row">
            <div class="toggle-copy">
              <strong>Encryption</strong>
              <span>Enable XOR encryption for ESP-NOW packets.</span>
            </div>
            <input class="toggle-input" type="checkbox" id="espnowEncryptionEnabled" name="espnowEncryptionEnabled" __ESPNOW_ENCRYPTION_ENABLED__>
          </div>
          <div class="field-grid two conditional" id="espNowEncryptionFields">
            <div class="form-group">
              <label class="form-label" for="espnowEncryptionKey">Encryption Key</label>
              <input class="form-input" type="text" id="espnowEncryptionKey" name="espnowEncryptionKey" value="__ESPNOW_ENCRYPTION_KEY__">
              <div class="form-hint">Use gateway format like ["0x4B","0xA3","0x3F","0x9C"]</div>
            </div>
          </div>
        </div>
      </section>

      <section class="section conditional" id="commonWifiFields">
        <div class="section-head">
          <div>
            <div class="section-title">WiFi Access</div>
            <div class="section-copy">Credentials shared by Fast-WIFI and Basic-WIFI.</div>
          </div>
        </div>
        <div class="field-grid two">
          <div class="form-group">
            <label class="form-label" for="ssid">WiFi SSID</label>
            <input class="form-input" type="text" id="ssid" name="ssid" value="__SSID__">
          </div>
          <div class="form-group">
            <label class="form-label" for="password">WiFi Password</label>
            <input class="form-input" type="password" id="password" name="password" value="__PASSWORD__">
          </div>
        </div>
      </section>

      <section class="section conditional" id="wifiAdvancedFields">
        <div class="section-head">
          <div>
            <div class="section-title">Fast-WIFI Network Details</div>
            <div class="section-copy">These values are only used in Fast-WIFI mode.</div>
          </div>
        </div>
        <div class="field-grid two">
          <div class="form-group">
            <label class="form-label" for="macAddress">AP MAC Address</label>
            <input class="form-input" type="text" id="macAddress" name="macAddress" value="__MAC_ADDRESS__">
            <div class="form-hint">Use the radio interface MAC address of your access point.</div>
          </div>
          <div class="form-group">
            <label class="form-label" for="wifiChannel">WiFi Channel</label>
            <input class="form-input" type="text" id="wifiChannel" name="wifiChannel" value="__WIFI_CHANNEL__">
            <div class="form-hint">The access point must use a fixed WiFi channel.</div>
          </div>
          <div class="form-group">
            <label class="form-label" for="localIP">Local IP</label>
            <input class="form-input" type="text" id="localIP" name="localIP" value="__LOCAL_IP__">
            <div class="form-hint">Use a free IP address from your local range and reserve it for this sensor.</div>
          </div>
          <div class="form-group">
            <label class="form-label" for="gateway">Gateway</label>
            <input class="form-input" type="text" id="gateway" name="gateway" value="__GATEWAY__">
          </div>
          <div class="form-group">
            <label class="form-label" for="subnet">Subnet</label>
            <input class="form-input" type="text" id="subnet" name="subnet" value="__SUBNET__">
          </div>
        </div>
      </section>

      <section class="section conditional" id="mqttFields">
        <div class="section-head">
          <div>
            <div class="section-title">MQTT Broker</div>
            <div class="section-copy">These fields are only needed for WiFi-based modes.</div>
          </div>
        </div>
        <div class="field-grid two">
          <div class="form-group">
            <label class="form-label" for="mqttserver">MQTT Server</label>
            <input class="form-input" type="text" id="mqttserver" name="mqttserver" value="__MQTT_SERVER__">
          </div>
          <div class="form-group">
            <label class="form-label" for="mqttport">MQTT Port</label>
            <input class="form-input" type="text" id="mqttport" name="mqttport" value="__MQTT_PORT__">
          </div>
          <div class="form-group">
            <label class="form-label" for="mqttusername">MQTT Username</label>
            <input class="form-input" type="text" id="mqttusername" name="mqttusername" value="__MQTT_USERNAME__">
          </div>
          <div class="form-group">
            <label class="form-label" for="mqttpassword">MQTT Password</label>
            <input class="form-input" type="password" id="mqttpassword" name="mqttpassword" value="__MQTT_PASSWORD__">
          </div>
        </div>
      </section>

      <section class="section">
        <div class="section-head">
          <div>
            <div class="section-title">Calibration</div>
            <div class="section-copy">Capture the current raw soil moisture reading and save it as your dry or moist calibration point.</div>
          </div>
        </div>
        <div class="status-row">
          <div class="status-chip live-chip">
            <strong>SOIL SENSOR RAW VALUE "LIVE"</strong>
            <span id="calibrationRawValue">__CALIBRATION_RAW__</span>
          </div>
        </div>
        <div class="status-row two-col">
          <div class="status-chip dry-chip">
            <strong>Dry Soil</strong>
            <span id="dryCalibrationValue">__DRY_SOIL_VALUE__</span>
          </div>
          <div class="status-chip moist-chip">
            <strong>WET SOIL</strong>
            <span id="wetCalibrationValue">__WET_SOIL_VALUE__</span>
          </div>
        </div>
        <div class="actions calibration-actions">
          <button class="btn btn-secondary btn-calibration btn-dry" type="button" id="captureDrySoil">SET DRY SOIL</button>
          <button class="btn btn-secondary btn-calibration btn-wet" type="button" id="captureWetSoil">SET WET SOIL</button>
        </div>
        <input type="hidden" id="drySoilCalibration" name="drySoilCalibration" value="__DRY_SOIL_VALUE_RAW__">
        <input type="hidden" id="wetSoilCalibration" name="wetSoilCalibration" value="__WET_SOIL_VALUE_RAW__">
        <div class="footer-note">Place the sensor in the target condition first, then capture the raw value and save configuration.</div>
      </section>

      <section class="section">
        <div class="actions settings-actions">
          <button class="btn btn-primary btn-half" type="submit">Save Configuration</button>
          <button class="btn btn-secondary btn-half" type="button" onclick="window.location.reload()">Reload Values</button>
        </div>
        <button class="btn btn-danger btn-full" type="submit" formaction="/reset-defaults" formmethod="post">Reset to Default</button>
        <div class="footer-note">Save stores the current settings. Reset to Default clears saved settings and loads the firmware defaults after restart.</div>
      </section>
    </form>
  </div>

  <script>
    let calibrationPollHandle = null;

    async function fetchCalibrationRawValue() {
      const response = await fetch('/calibration-raw', { cache: 'no-store' });
      if (!response.ok) throw new Error('Failed to read soil calibration value');
      return response.json();
    }

    async function refreshCalibrationRawValue() {
      try {
        const payload = await fetchCalibrationRawValue();
        document.getElementById('calibrationRawValue').textContent = String(payload.rawValue);
      } catch (error) {
      }
    }

    async function captureCalibration(target) {
      try {
        const payload = await fetchCalibrationRawValue();
        const rawValue = String(payload.rawValue);
        document.getElementById('calibrationRawValue').textContent = rawValue;
        if (target === 'dry') {
          document.getElementById('dryCalibrationValue').textContent = rawValue;
          document.getElementById('drySoilCalibration').value = rawValue;
        } else {
          document.getElementById('wetCalibrationValue').textContent = rawValue;
          document.getElementById('wetSoilCalibration').value = rawValue;
        }
      } catch (error) {
        alert(error.message);
      }
    }

    function toggleFields() {
      var selected = document.querySelector('input[name="mode"]:checked');
      var mode = selected ? selected.value : '0';
      var encryptionToggle = document.getElementById('espnowEncryptionEnabled');
      var encryptionEnabled = encryptionToggle ? encryptionToggle.checked : false;
      document.getElementById('gatewayKeyField').classList.toggle('show', mode === '1');
      document.getElementById('espNowEncryptionBlock').classList.toggle('show', mode === '1');
      document.getElementById('espNowEncryptionFields').classList.toggle('show', mode === '1' && encryptionEnabled);
      document.getElementById('commonWifiFields').classList.toggle('show', mode !== '1');
      document.getElementById('wifiAdvancedFields').classList.toggle('show', mode === '0');
      document.getElementById('mqttFields').classList.toggle('show', mode !== '1');
    }
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
void loop() {
  if (config_mode == 1) {
    modeESPNOW();
  } else {
    if (WiFi.status() != WL_CONNECTED) {
      if (config_mode == 0) {
        fast_setup_wifi();
      } else if (config_mode == 2) {
        basic_setup_wifi();
      }
    }

    if (client.connected() && !mqttPublished) {
      publishmqtt();
      mqttPublished = true;
      toggleStartTime = millis();
    } else if (!client.connected()) {
      reconnect();
    }

    client.loop();

    if (millis() - toggleStartTime >= 500 && mqttPublished) {
      toggleDonePin();
    }
  }

  FailSafe();
  client.loop();
}

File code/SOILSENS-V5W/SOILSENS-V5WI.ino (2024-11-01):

#include <esp_now.h>
#include <WiFi.h>
#include "driver/adc.h"
#include "esp_adc_cal.h"
#include "Wire.h"
#include <SparkFunTMP102.h>
#include <ArduinoJson.h>
#include <AHT20.h>
#include <Preferences.h>
#include <WebServer.h>
#include <PubSubClient.h>

#define DEFAULT_VREF 1100
#define MQTT_RETAIN true
#define SENSOR_TOPIC "homeassistant/sensor/"
uint8_t receiverAddress[] = {0xFF, 0xFF, 0xFF, 0xFF, 0xFF, 0xFF}; // ESP-NOW Receiver MAC "BROADCAST"

bool mqttAutodiscoverySent = false;

AHT20 aht20;
TMP102 sensor0;
Preferences preferences;

const int calibrationButtonPin = 7;
const int blueLEDPin = 2;
const int soilMoisturePin = 3;

unsigned long buttonPressTime = 0;
const unsigned long minPressTime = 500;
const unsigned long maxPressTime = 2000;

unsigned int drySoilValue;
unsigned int wetSoilValue;

int light;
int batteryPercentage;
int soilMpercent;
String node_name;
String gateway_key;
String wifi_ssid;
String wifi_password;
String mqtt_server;
unsigned int mqtt_port;
String mqtt_username;
String mqtt_password;
String local_ip;
String gateway;
String subnet;
String mac_address;
unsigned int wifi_channel;
unsigned int config_mode; 

StaticJsonDocument<256> doc;

typedef struct struct_message {
    char json[256];
} struct_message;

struct_message myData;

WiFiClient espClient;
PubSubClient client(espClient);

void setup_wifi() {

  //Serial.println();
  //Serial.print("Connecting to ");
  //Serial.println(wifi_ssid);

  WiFi.persistent(true); 
  WiFi.mode(WIFI_STA);
  
  IPAddress localIP;
  IPAddress gatewayIP;
  IPAddress subnetMask;
  
  localIP.fromString(local_ip);
  gatewayIP.fromString(gateway);
  subnetMask.fromString(subnet);

  WiFi.config(localIP, gatewayIP, subnetMask);
  
  uint8_t my_bssid[6];
  sscanf(mac_address.c_str(), "%hhx:%hhx:%hhx:%hhx:%hhx:%hhx", &my_bssid[0], &my_bssid[1], &my_bssid[2], &my_bssid[3], &my_bssid[4], &my_bssid[5]);

  WiFi.begin(wifi_ssid.c_str(), wifi_password.c_str(), wifi_channel, my_bssid);
  
  uint32_t timeout = millis() + 5000;

  while (WiFi.status() != WL_CONNECTED && millis() < timeout) {
    delay(500);
    Serial.print(".");
  }

  if (WiFi.status() == WL_CONNECTED) {

    Serial.println("");
    Serial.println("WiFi connected");
    Serial.println("IP address: ");
    Serial.println(WiFi.localIP());
  } else {
    Serial.println("Failed to connect to WiFi");
  }
}



void reconnect() {
  while (!client.connected()) {
    Serial.print("Attempting MQTT connection...");
    // Buffer needs to be increased to accomodate the config payloads
    if (client.setBufferSize(1024)) {
      Serial.println("Buffer Size increased to 512 byte");
    } else {
      Serial.println("Failed to allocate larger buffer");
    }

    String client_id = node_name;

    if (client.connect(client_id.c_str(), mqtt_username.c_str(), mqtt_password.c_str())) {
      Serial.println("MQTT connected");

      Serial.println("Buffersize: " + client.getBufferSize());

    } else {
      Serial.print("MQTT failed, rc=");
      Serial.print(client.state());
      Serial.println(" try again in 1 seconds");
      delay(1000);
    }
  }
}


void setup() {
    Serial.begin(115200);
    Wire.begin(6, 5);
    // Retrieve the saved data from Preferences
    preferences.begin("wifi-config", true);
    wifi_ssid = preferences.getString("ssid", "ssid");
    wifi_password = preferences.getString("password", "password");
    node_name = preferences.getString("nodeName", "SOILSENS-V5W");
    gateway_key = preferences.getString("gatewayKey", "ab");
    config_mode = preferences.getUInt("mode", 1);
    mqtt_server = preferences.getString("mqttserver", "192.168.2.20");
    mqtt_port = preferences.getUInt("mqttport", 1883);
    mqtt_username = preferences.getString("mqttusername", "mqtt");
    mqtt_password = preferences.getString("mqttpassword", "Mqttpass");
    local_ip = preferences.getString("localIP", "192.168.2.19");
    gateway = preferences.getString("gateway", "192.168.2.1");
    subnet = preferences.getString("subnet", "255.255.255.0");
    mac_address = preferences.getString("macAddress", "94:a6:7e:99:99:99");
    wifi_channel = preferences.getUInt("wifiChannel", 6);
    preferences.end();

    pinMode(calibrationButtonPin, INPUT);
    pinMode(blueLEDPin, OUTPUT);
    digitalWrite(blueLEDPin, HIGH);
    pinMode(4, OUTPUT);
    digitalWrite(4, LOW);

    adc1_config_width(ADC_WIDTH_BIT_12);
    adc1_config_channel_atten(ADC1_CHANNEL_0, ADC_ATTEN_DB_11);
    adc1_config_channel_atten(ADC1_CHANNEL_1, ADC_ATTEN_DB_11);
    adc1_config_channel_atten(ADC1_CHANNEL_3, ADC_ATTEN_DB_11);

    if (digitalRead(calibrationButtonPin) == LOW) {
        buttonPressTime = millis();
        while (digitalRead(calibrationButtonPin) == LOW) {}
        if (digitalRead(calibrationButtonPin) == HIGH) {
            unsigned long pressDuration = millis() - buttonPressTime;
            if (pressDuration > minPressTime && pressDuration < maxPressTime) {
                calibrateSoilMoistureSensor();
            } else if (pressDuration >= maxPressTime) {
                blinkLED(6, 100);
                setupSensorConfig();
            }
        }
    }

    // Check mode ESP-NOW or WIFI
    if (config_mode == 1) {
        WiFi.mode(WIFI_STA);
        if (esp_now_init() != ESP_OK) {
            Serial.println("Error initializing ESP-NOW");
            return;
        }

        esp_now_peer_info_t peerInfo;
        memcpy(peerInfo.peer_addr, receiverAddress, 6);
        peerInfo.channel = 0;
        peerInfo.encrypt = false;

        if (esp_now_add_peer(&peerInfo) != ESP_OK) {
            Serial.println("Failed to add peer");
            return;
        }

        esp_now_register_send_cb(OnDataSent);
    } else {
        // Code to execute if config_mode is not equal to 1
        setup_wifi();
        client.setServer(mqtt_server.c_str(), mqtt_port);
        reconnect();
    }


    if (!sensor0.begin()) {
        Serial.println("TMP102 not detected.");
        while (1);
    }

    if (aht20.begin() == false) {
        Serial.println("AHT20 not detected.");
        pinMode(3, OUTPUT);
        digitalWrite(3, LOW);
        while (1);
    }

    preferences.begin("soilCalib", true); // Read-only mode
    drySoilValue = preferences.getUInt("drySoilValue", 0);
    wetSoilValue = preferences.getUInt("wetSoilValue", 0);
    preferences.end();

}

void OnDataSent(const uint8_t *mac_addr, esp_now_send_status_t status) {
    toggleDonePin();
}

int getAverageSoilMoisture() {
    int total = 0;
    for (int i = 0; i < 5; i++) {
        int soilMoisture = adc1_get_raw(ADC1_CHANNEL_3);
        total += soilMoisture;
    }
    int average = total / 5;
    return average;
}


int getAverageVoltage() {
    int total = 0;
    for (int i = 0; i < 5; i++) {
        int adcRow = adc1_get_raw(ADC1_CHANNEL_0);
        total += adcRow;
    }
    int averageVolts = total / 5;
    return averageVolts;
}
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

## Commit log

2024-07-28 batt calibration
2024-08-06 3D Went for Air sensor
    [SoilSens-V5W_Base.SLDPRT, SoilSens-V5W_Base.STL, SoilSens-V5W_Top_Went.SLDPRT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]
2024-08-06 Vent for air sensor
    [SoilSens-V5W_Top_Vent.SLDPRT, SoilSens-V5W_Top_Vent.STL]
2024-08-19 Base with bigger gap
    [SoilSens-V5W_Base.SLDPRT, SoilSens-V5W_Base.STL, SoilSens-V5W_Base_DIY.SLDPRT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]
2024-11-01 Update SOILSENS-V5WI.ino
    Calibration delay 10sec
2024-11-01 PCB Gerbers
    [bom_list.xlsx]
2024-11-01 Update README.md
    Schematic
2026-04-17 Web_UI
    New UI and Calibration
2026-04-17 Update README to remove sensor setup troubleshooting note
    Removed troubleshooting note for sensor setup.
2026-04-20 Enhance wet calibration instructions for accuracy
    Added note for best accuracy during wet calibration.
2026-04-28 Clarify soil moisture sensor calibration steps
    Updated instructions for calibrating the soil moisture sensor for clarity and best practices.
